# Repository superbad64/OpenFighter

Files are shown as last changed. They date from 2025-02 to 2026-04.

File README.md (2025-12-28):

  

# Open-source 3D printable fightstick cases for the crafty warrior

A gaggle of case builds intended to be mostly 3D printed.

## How's it works

Builds are assigned (very subjective) stats on a scale of 1 to 5 vaguely describing what my own experience was putting them together:  

- **Printability**: How easy they are to print. Most of the time PLA is assumed to be the material of choice. 5 means if your machine squirts plastic it should work; 1 means you pretty much need a perfectly tuned printer to do it. Anything below 1 means it has only ever worked on my personal printers during what can be generously called a freak accident.
- **Buildability**: How easy they are to actually put together. 5 should be roughly equal to your average LEGO Technic build; 1 means you need a PhD in rocket surgery.
- **Extra hardware**: How much non-printed hardware and tools is needed to build (generally proportional to the price). **This only concerns the case itself; electronics are not considered part of it** (except when noted). 5 means you only need heat-set inserts and corresponding screws at best; 1 means you need to source some stuff that may be harder than average to get. (Do note that usually acrylic is considered "to taste" and doesn't factor into this particular note)
- and finally, **Price**: Because of course this is a deciding factor for a lot of people. 5/5 means it's super cheap to make; 1/5 means I had to sell my house to make it.

## The gallery

Goblin: Flatbox-style build  
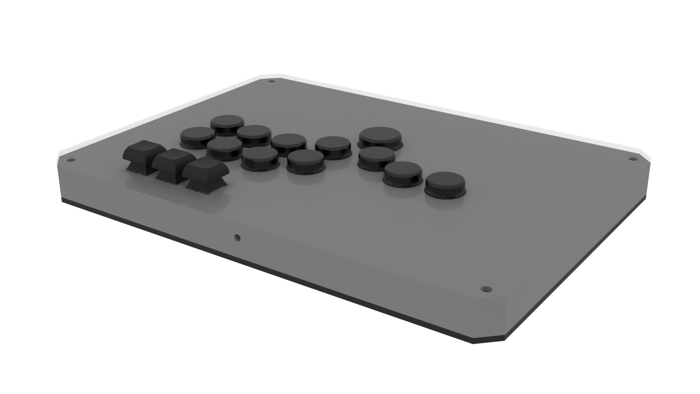
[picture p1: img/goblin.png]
Goblin


Ikari: Tented ergonomic build
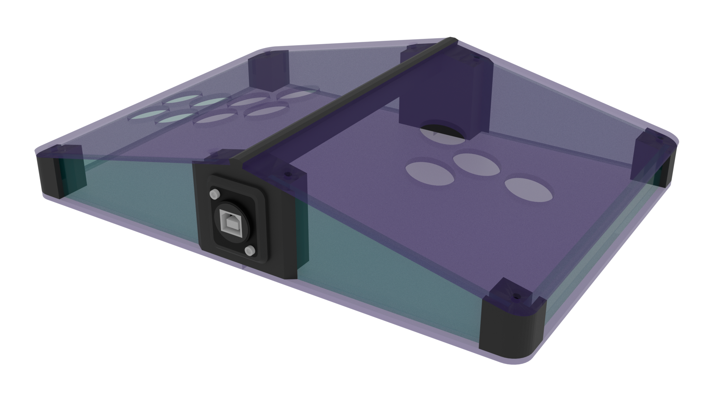
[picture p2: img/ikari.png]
Ikari


Ogre: American-style build
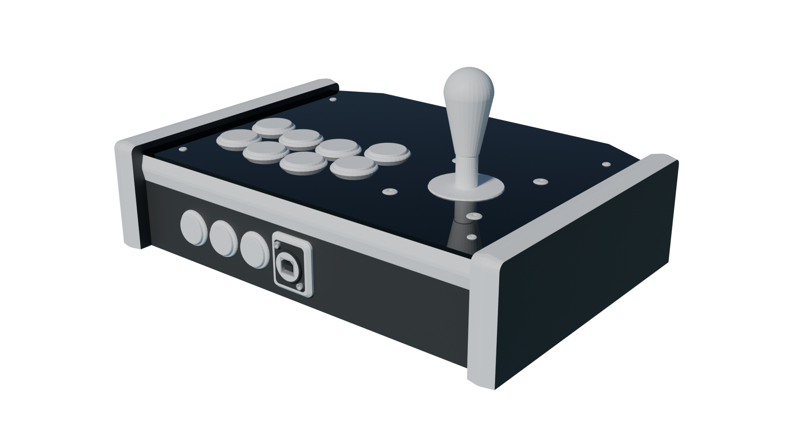
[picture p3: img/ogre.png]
Ogre


Ork: All-rounder compact build
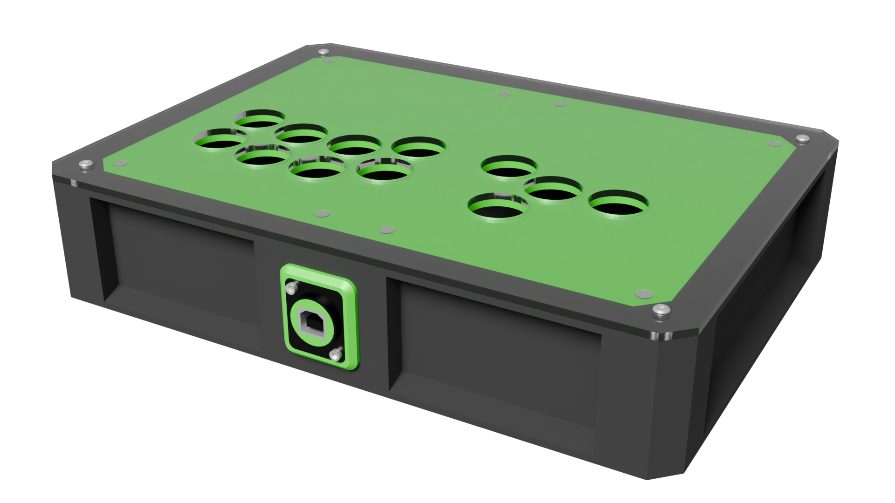
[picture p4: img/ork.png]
Ork


Unhinged: Clamshell design for easy access to the internals
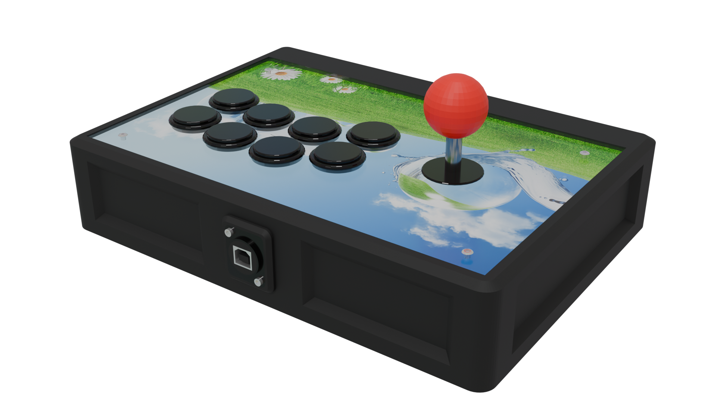
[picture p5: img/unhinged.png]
Unhinged


Wanderer: Cheap straightforward build
Wanderer

Tteokbokki Top Grade: Rough equivalent to "OC Do Not Steal"
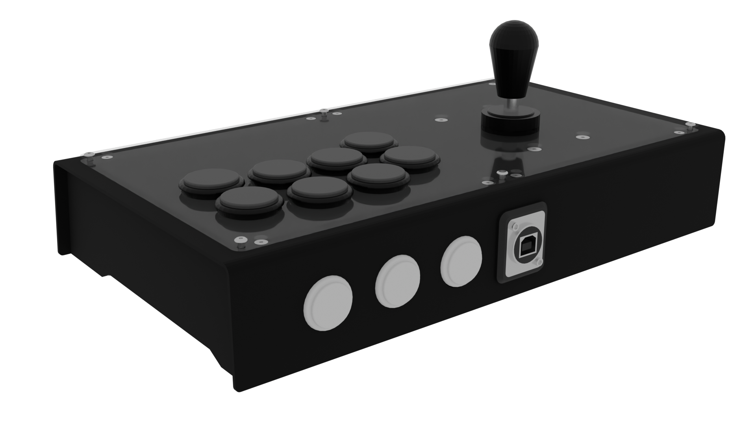
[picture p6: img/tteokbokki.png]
Tteokbokki


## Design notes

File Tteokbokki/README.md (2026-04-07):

# T.T.E.O.K.B.O.K.K.I. Top Grade Case
## Also known as "We have [REDACTED] at home"

Non-copyright-infringing case

---

A case that I swear no one has ever seen around. Comes with a magnetically attached bottom plate (if you want it to; otherwise it's M3 Screw Land).

## The Stats

**Printability**: 4/5; You do need a setup that is particularly good at bevels and supports; I use tree supports for the frame  
**Buildability**: 4/5; Large, roomy case with plenty of internal space  
**Extra hardware**: 3/5; Does need a fair amount of screws, and also magnets  
**Price**: 4/5; The hardware drives the BOM up a little on this one but nothing too cray cray  

## Some context and questions I've been asked about it

A few months ago I made the [Raijin](https://github.com/superbad64/OpenFighter/tree/main/Personal%20Builds/Raijin) out of a desire to have a full-collar Korean build. Due to the frankly ludicrous BOM on it, I decided to revisit it, and the end result happened to be this very build.

For printability's sake I made one with full sides, instead of the recessed ones pictured above. The files for it are also available in the STL folder.

Do keep in mind that this was *supposed* to be filled, sanded, primed, and then painted to hide the joint seams; therefore some of the conception really does not account for a default "extruded plastic" look. (It works though, but that's more a happy accident than anything else)

## Parts list

Must be exactly matched:

- M3S Ruthex heat-set inserts:
    - 6 for the acrylic
    - 8 for the top panels
    - 8 more if you're using the screw-on bottom
- 1x A3-sized 2 or 3mm thick sheet of material to drill or laser cut for the top panel (acrylic, wood, brass, dry ice, aerogel...)

Exact match not needed except for dimensions:

- DIN 7991/ISO 10642 M3x8 hex socket countersunk screws for the top panel halves
    - 8 for the top panel halves
    - 8 more if you want the screw-on bottom panel
- 6x ISO 7380 M3x8 hex socket button head screws for the acrylic
- 4x DIN 7991/ISO 10642 M4x16 hex socket countersunk screws to mount the lever (if you choose to have one of course)
    - In a pinch, M3x16 also works as long as you're using a washer
- 2x DIN 912/ISO 4672 M3x30 hex socket head cap screws for the Neutrik
- M3 nuts and washers (just grab a handful)
- 8 or 12x 15 by 3 millimeters disc-shaped magnets if you want the magnetic bottom (I find 8 to be largely enough but you do you)
- 4x 6x30mm dowel rods (you can just print them anyway, they're just cylinders)

Tools && auxiliaries:

- Soldering iron
- Multi-purpose pliers to tighten all those nuts
- Neoprene glue/contact cement
- (Optional but **vigorously** recommended) *Long* ratcheting clamps
- (Optional but recommended) Medium strength threadlocker, aka blue Loctite(tm)

## Build guide

Print both frame halves and carefully remove the supports. Insert the dowels in the guiding holes and join the halves together, using neoprene glue.

> [!IMPORTANT]
> While I'm unsure of the exact effects of neoprene glue fumes on the human body/nervous system, it seems like a good idea to avoid spreading said glue too close to the holes into which a heat-set insert is going to be added in a few moments.

If you have some, use the ratcheting clamps to make sure everything is super tight (you shouldn't *need* to but it can't hurt). Let the glue cure for a day.

Add the heat-set inserts to the holes on the top side. Screw in the top panels of your choice using the inner holes (relative to each panel); the outer holes are for the acrylic.

Use some more neoprene glue to attach half of the the magnets to the frame. Whilst being mindful of the polarity, attach the other half to the bottom panels.

Join the three bottom panel parts together using... you guessed it, neoprene glue. After curing, you can plastic weld the non-glued parts to further improve stability.

## TODO

- Art && cut files

## Acknowledgements

- [Buttercade](https://www.etsy.com/shop/BUTTERCADE) for the Surround and Support project
- [The GP2040-CE project](https://gp2040-ce.info) for the GP2040-CE firmware
- Sega for the Virtua Stick High Grade
- By proxy, Etokki for the Omni

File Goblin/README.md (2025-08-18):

# G.O.B.L.I.N.
## Flat case and a good weekend project

I was rendered in Cycles and took like an hour... but at least I'm not EEVEE

---

A Flatbox-style build in two flavors: WASD and Standard. Uses Cherry MX style switches, compatible with SiTong caps. Requires you to vaguely know how to operate both a 3D printer and a soldering iron.

The main difference with the OG Flatbox is that this is a bit chonkier, and uses regular keycaps for the options row.

## The Stats

**Printability**: 5/5 (very few supports, as long as you have a good bed level it should be a breeze)  
**Buildability**: 4/5 (you will need to have solid bases in soldering to get this done)  
**Extra hardware**: 4/5 (all of it can be easily bought online for cheap)  
**Price**: 5/5 (it's about the cheapest controller I can make)

## Materials needed

- 4x M4 x 20mm "Chicago bolts"
- 15x MX-style switches
- (Optional) 15x MX-style hotswap sockets (in case you want to change your switches further down the line)
- 12x round caps (see below)
- 3x square keyboard caps
- 4x 200 by 3mm metal rods (either brass or steel, to taste)
- A board capable of running GP2040-CE (I used a Waveshare RP2040-Zero)
- Wire (solid core && stranded)
- Wire strippers
- Soldering iron (preferably one with adjustable temperature)
- (Optional) Cuttable screw terminals, or Wago style terminals

## Printing

Print the chassis halves. Print the bottom pieces. Print the top pieces if that's what you want, or go get some acrylic laser cut.

I swear it's *that* straightforward.

## Building

Assemble the two top halves, using the rods for alignment and support. Put your outbound USB cable in the hole. Plastic weld or glue if you feel like it. Do the same for the bottom halves.

Insert all your switches in the square holes; they're friction fit. Save the caps for later.

Use the solid core wire to wrap hooks (or loops if you're really dextrous) around the pins of the switches. If you use hotswap sockets, you might need to strip some extra. Solder those hooks and go from pin to pin until you have grounded all your switches. (You don't need to ground them all on the same rail, it just helps if you have a limited number of ground pins)

At this point you have a couple of options, all valid:  
- Leave a length of solid core wire after you're done hooking everything up, connect it directly to a ground pin on whatever board you use
- Do the same but a shorter length, use a Wago or screw terminal, and continue your ground path to the board with a stranded core wire
- Directly wrap stranded core wire above/around the last ground pin in the chain and connect *that* to the board

Switch to stranded core from this point onwards.

Measure lengths of wire and strip one end (don't be afraid of overdrawing at the wire bank so to speak - it's best to measure twice and cut once than it is to try to splice bits of wire together afterwards). Solder that end into your board.Measure how long you need to go to a given switch pin, add a couple centimeters, strip the wire, and wrap it around the switch pin to solder it.

Now how you make the board communicate with the outside world (and hopefully with a host type device such as a PC or a game console) is up to you; there are a lot of boards and even more cables, panel mounted cables, breakout cables and so on, and I realistically can't cover every case.

I encourage you to closely inspect your wiring job at this point, and most importantly test it !

Once you're done, set the caps onto your switches. Support them from the back while doing so to avoid damaging your wires.

Place your art (optional) and the acrylic on your top panel. Add the Chicago screw barrels. Place the bottom plate and screw it in place.

Let the Ikea Effect wash over you for a couple minutes before hitting the lab.

## Button Caps

You pretty much have two ways of going about this:

- Obtain a set of SiTong 24mm caps; those are 20.6mm across and will fit perfectly (don't forget to get a 30mm one - which is actually 25mm across - for the Standard Leverless layout) , **OR**
- Print them yourself (PLA is not recommended although that depends on your particular brand; PETG is much better). [Rana-sylvatica's keycaps](https://github.com/rana-sylvatica/circle-keycaps/tree/main) are a good bet, but anything with a MX compatible stem that is less than 21mm across should be okay

## Acknowledgements

- [jfedor's Flatbox](https://github.com/jfedor2/flatbox) for being the OG inspiration
- [The GP2040-CE project](https://gp2040-ce.info) for being an awesome firmware and for their Discord server re-teaching me how to solder

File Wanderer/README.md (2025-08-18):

# W.A.N.D.E.R.E.R.
## Very simple build

Eye of newt and hair of Shelob, now everyone can see your bad wiring job

---

This case is intended for a (relatively) compact and simple build with all the features you'd normally expect in a modern fightstick, except art support.

## The Stats

**Printability**: 5/5 (nothing to talk about)  
**Buildability**: 5/5 (your little sister can probably do it)  
**Extra hardware**: 5/5 (nothing unusual either)
**Price**: 5/5 (as cheap as a full size case can get)

Really the only problem is that the case is a little plain looking. YMMV.

## Parts list

Must be exactly matched:

- 16x M3S Ruthex heat-set inserts
- 1x Neutrik NA-USB

Exact match not needed except for dimensions:

- 16x DIN 7991/ISO 10642 M3x8 hex socket countersunk screws
- 2x DIN 912/ISO 4672 M3x35 hex socket head cap screws for the Neutrik
- 2x DIN 934/ISO 4032 M3 hex nuts

It's Whatever (tm):

- 3mm thick material for the sides (acrylic, 3D printed plastic, wood, metal, cardboard, marble, dry ice...)

Tools && auxiliaries:

- Soldering iron
- (Optional but recommended) Medium strength threadlocker, aka blue Loctite(tm)

## Build guide

Print the two center joints (`centerfront` and `centerbottom`) upside down to minimize support usage.

Print the four corner posts (`post`) and add the magnets at the bottom, checking that they have the same polarity.

Print the bottom pieces, add the magnets while being careful that the polarity matches with those on the posts (in case this needs to be said outright, the posts should all attract the bottom plates).

At this point you have two (not mutually exclusive) choices:

### The Laser Way

Congratulations, you found a couple of nice sheets of 3mm thick material !  
Bring the laser cut files to your favorite shop and laser away. It's kind of that simple.

### The Printer Way

Actually it's mostly the same thing, except you just upload the STL files to your printer and wait the requisite amount of hours. (Specifically: one `left`, one `right`, and four `bridge` for the sides; and both halves of whichever top you pick)

### Moving on

Assemble the frame pieces together, without the corner posts. Slot in your top panels, and then screw the posts in. Optionally, weld the top panel halves together from the inside.

Add your electronics (I know, this is a vague step, but that's as general as I need it to be)

Screw in your bottom panel (you can also weld it from the inside).

Boom, fightstick !

## TODO:

- HitBox
- WASD

## Acknowledgements

- [Buttercade](https://www.etsy.com/shop/BUTTERCADE) for the Surround and Support project
- [Arcade Shock](https://arcadeshock.com/products/fs-traveler-acrylic-controller-case-choose-type) for the Traveler which largely inspired this project

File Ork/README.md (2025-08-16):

# O.R.K.
## Regular fightstick case

> [!NOTE]
> This case is currently being remade from scratch. Stay tuned !

Waaaaagh !

---

An all-around, semi-compact case that has the footprint of an A4 sheet. Supports art prints.

## The Stats

**Printability**: 5/5 (no gimmicks)  
**Buildability**: 4/5 (press-fit is a little hard but nothing insurmountable)  
**Extra hardware**: 5/5 (nothing outside of acrylic and heat set inserts)  
**Price**: 4.5/5 (it does need a lot of filament but nowhere near the Ogre, so it's still fairly cheap)

## Parts list

Must be exactly matched:

- 20x M3S Ruthex heat-set inserts:
    - 8 for the bottom panels
    - 8 for the top panels
    - 4 for the acrylic
- 1x A4-sized 3mm thick sheet of material to laser cut for the top panel (acrylic, wood, brass...)

Exact match not needed except for dimensions:

- 4x ISO 7380 M3x5 hex socket button head screws for the acrylic
- 24x DIN 7991/ISO 10642 M3x8 hex socket countersunk screws:
    - 8 for the bottom panel
    - 8 for the top panel
    - 4 for the acrylic
    - 4 to mount the lever (if applicable)
- 4x DIN 7991/ISO 10642 M4x10 hex socket countersunk screws to mount the lever
- 2x DIN 912/ISO 4672 M3x30 hex socket head cap screws for the Neutrik
- 4x M3 washer (also for the lever if there is one)
- 6x DIN 934/ISO 4032 M3 hex nuts

Tools && auxiliaries:

- Soldering iron
- (Optional but recommended) Neoprene glue/contact cement. CA glue should work too
- (Optional but recommended) Medium strength threadlocker, aka blue Loctite(tm)

## Build guide

Print four corner pieces, the left and right ones, front and back dividers, the four short sides, then the bottom file twice. Press fit all parts of the frame together (clamps might help). Add heat set inserts.

Pick a layout and print the top plates. Screw them to the frame. Get your art printed, your acrylic cut, and add them to the top. Secure with screws.

Time to build the electronics !

## TODO

- Sega 2P layout
- Better render
- All art & cut files

## Acknowledgements

- [Buttercade](https://www.etsy.com/shop/BUTTERCADE) for the Surround and Support project
- [Junk Food Arcades](https://junkfoodarcades.com) for the Snack Box v2, which genuinely coincidentally happen to share a lot of general shapes with this project)
- [The GP2040-CE project](https://gp2040-ce.info) for the GP2040-CE firmware

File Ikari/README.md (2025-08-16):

# I.K.A.R.I.
## Tented ergonomic build

> [!NOTE]
> This is a WIP ! It's not yet quite ready to be actually brought into the physical world.  
> *Hic sunt dracones.*

Fiendishly plotting

---

Sloped build to reduce wrist pain. Originally envisioned as a pure acrylic cut build, turns out it's also printable (who knew lmao). More info to come SOON(tm)

## The Stats

**Printability**: ?/5 (I haven't actually built one, but all the pieces are extremely simple geometry, so it should be a 5)  
**Buildability**: ?/5 (ditto)  
**Extra hardware**: Probably 1/5 if you run it in full laser cut acrylic as intended, and 5/5 if you print it (again, still haven't built one)  
**Price**: Probably -2/5 for the acrylic, and 5/5 for the printed one

## Parts list
TODO

## Build guide
Also TODO

## Acknowledgements

- [Buttercade](https://www.etsy.com/shop/BUTTERCADE) for the Surround and Support project
- [Arcade Shock](https://arcadeshock.com/products/fs-traveler-acrylic-controller-case-choose-type) for the Traveler which largely inspired this project

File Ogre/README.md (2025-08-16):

# O.G.R.E.
## American-style fightstick case

\<Kazoo rendition of The Star-Spangled Banner.mp3\>

---

## The Lore

This case is based on the venerable Multi Arcade System by the legendary Thao Nguyen (may he and his wife rest in peace). There are major differences though, which is why I call it an American-*style* case, rather than being a straight tribute.

The first and most obvious is the building material. Original MAS sticks were made of thick MDF, and while it's a nice building material, it also weighs a ton. I'm pretty confident that any printable plastic, even at 100% infill density, will result in a case that is *far* lighter than any MAS ever was. (*Note: I don't actually have a MAS so if you have one and can prove me wrong I'd actually genuinely appreciate it*)

To preserve at least the spirit if not the letter, laser cut files are provided for additional wooden accents to be glued onto the frame. MDF or plywood should work nicely as long as it's 3mm thick. Even acrylic if you're feeling adventurous and decide to slice the "wings" without top and bottom surfaces so as to partially see inside the stick. But should you want to, you could also just print them in a different color from the end of the frame !

The second major difference, also rather obvious, is that I elected to not slope the control panel inwards. To be honest I couldn't find data on what angle should be used, and since I am going to use that as a lap stick anyway, I decided to forgo this part entirely.

Third big difference: The button layout has been adapter to something more hand-friendly (namely Sega 2P) and uses 30mm holes instead of the 28mm ones made for Happ-style buttons (including IL versions).

And the last difference: the build is a lot smaller than an original MAS (again done to be able to use it on my lap). The original is 40.64 x 25.40 x 12.7 centimeters, and this one is 32.8 x 23.2 x 7.8 centimeters.

## The Stats

**Printability**: 3.5/5 (the external walls/"wings" really suck and take way too much time to print, and every grooved part needs support due to orientation)  
**Buildability**: 5/5 (super roomy case that is very easy to put together and build in)  
**Extra hardware**: 4/5 (technically you could print the dowels using a truncated cylinder, but the square neck bolts is where it loses a point for real)  
**Price**: 4/5 (eats about an entire roll of plastic to be willed into existence; not too bad but definitely the most expensive build I have on the roster)

## Parts list

Must be exactly matched:

- 28x 6x30 wood dowels
- 16x M3S Ruthex heat-set inserts (I haven't tested other ones, and I know *those* work)
- 1x Neutrik NA-USB
- 4x DIN 603/ISO 8678 M5x30 cup head square neck bolts (**THE SQUARE NECK IS IMPORTANT**)

Exact match not needed except for dimensions:

- 4x DIN 6923/ISO 4162 M5 hex nuts with flange (any M5 fastener will work but these are the ones I used)
- 4x ISO 7380 M3x8 hex socket button head screws
- 8x DIN 7991/ISO 10642 M3x6 hex socket countersunk screws
- 2x DIN 912/ISO 4672 M3x30 hex socket head cap screws
- 2x DIN 934/ISO 4032 M3 hex nuts

To taste:

- About a kilogram of filament (more if you wish to print accent pieces)
- Around 1m of T-molding, 19mm wide

Tools & auxiliaries:

- Soldering iron
- (Optional but recommended) A rubber mallet
- (Optional but recommended) Neoprene glue/contact cement. CA glue should work too
- (Entirely optional) Around 2 A4 sheets worth of 3mm thick material to laser cut
- (Entirely optional) One A3 size 3mm acrylic sheet for the top panel, also for laser cutting

## Build guide

> [!IMPORTANT]
> Currently the mounting points for the main board are misaligned.
> **I am aware of this.**
> If that is a problem for you, a temporary fix would be to use self-adhesive feet, but really you can pretty much leave the board hanging in there too. I will eventually fix this some day.

Start with the two main body halves and the support bracket, all located in the Common folder. Use five dowels (and glue if you have to) to join the halves. Add the heat-set inserts: 6 holes on the underside of the body, 2 in the support bracket, ~~4 holes on the right side to mount the board~~, and 4 holes on top to mount the acrylic.

Print both sides of the fender, and join them with one dowel. Add four more (and again, glue if you need to) then join it to the main body. This will also lock the main body permanently !

Add the T-molding to the main body. Use whatever you deem necessary to make it behave and slot in properly. Glue, clamps, heat gun -- anything is fair game.

Depending on whether you're going for accent panels or not, pick your wing model from the appropriate folder. The wings are symmetrical, so start with whichever side you find more convenient. Add dowels to the main body; if you're hammering them in, only hammer the 6 outer ones in since the 3 middle holes do not bottom out !

- If you're going for the layered approach: go for (glue) -> side with holes -> (glue) -> inner wing -> (more glue) -> outer wing -> t-molding
- If not, just slide it in and add your t-molding after

Screw in your top panel acrylic if you have one; add the square neck bolts to your top panel and secure them (if you already have the lever on hand, it's time to install it as well)

Add the Neutrik to the main body, then the support bracket

Print the bottom piece twice and screw it to the body.

## FAQs:

Q: Which levers are compatible with this ?  
A: This case is made for the Industrias Lorenzo Eurostick 2. For any other lever, you will need an adapter plate. I do not know *which* adapter plate though, sorry !

Q: Which buttons are compatible with this ?  
A: They should all be compatible. You might have trouble fitting Happ-style buttons without a shim (just a hollow barrel or ring, ID 28.1mm OD 29.9mm 3mm high if you wanna model one yourself)

Q: Can I print the parts that should be made of wood/acrylic ?  
A: Sure ! Contact cement works just as well to attach them.

Q: T-molding is a PITA ! Any suggestions to deal with it ?  
A: Frankly I used weak adhesive (read: regular school-grade glue) to make mine behave. If you have a heat gun that also works, just be careful to not melt the plastic !

## Acknowledgements

- The Nguyen family of course, for creating the MAS in the first place, and by proxy the very concept of fightsticks
- [Buttercade](https://www.etsy.com/shop/BUTTERCADE) for the Surround and Support project

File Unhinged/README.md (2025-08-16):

# The Unhinged
## Fabled clamshell design of legend

> [!NOTE]
> This build will probably be either deleted or remade from scratch to address some of the building issues.

Ironically, very much hinged

This compact build offers a clamshell design for easy access to the internals.

## The Stats

**Printability**: 5/5 (none of the pieces are hard to print, but...)  
**Buildability**: 2/5 (...there are lots of problems to actually put the lid together)
**Extra hardware**: 2/5 (the door ball catch is *really* specific)
**Price**: 3.5/5 (not too bad but the hinge hardware does affect the final BOM)

## Parts list

Must be exactly matched:

- At least 16x M3S Ruthex heat-set inserts (I haven't tested other ones, and I know *those* work):
    - 6 for the bottom panel
    - 2 for the door catch
    - 8 for the hinge bases
    - Add 4 more if you're using a lever
- 1x Neutrik NA-USB
- Door ball catch, 40mm long, with M4 holes 34mm apart (center to center)
- 1x A4 sized 3mm thick sheet of material to laser cut for the top panel (acrylic, wood, brass...)

Exact match not needed except for dimensions:

- 4x ISO 7380 M3x8 hex socket button head screws for the acrylic
- 6x DIN 7991/ISO 10642 M3x8 hex socket countersunk screws for the bottom panel
- 2x DIN 912/ISO 4672 M3x8 hex socket head cap screws for the door catch (the holes are M4 but the wider head works to hold it down fine)
- 6x DIN 912/ISO 4672 M3x25 hex socket head cap screws for the hinges (technically you need 4 M3x25 and 2 M3x10)
- 2x DIN 912/ISO 4672 M3x30 hex socket head cap screws for the Neutrik
- 12x DIN 934/ISO 4032 M3 hex nuts:
    - 4 for the top panel
    - 6 for the hinges
    - 2 for the Neutrik

Tools && auxiliaries:

- Soldering iron
- (Optional but recommended) Neoprene glue/contact cement. CA glue should work too
- (Optional but recommended) Medium strength threadlocker, aka blue Loctite(tm)

## Build guide

Print all parts of the frame (`left`, `right`, `centerfront` and `centerback` STLs), and 12 `dowel`. Join the parts together, using adhesive if you want to make sure the frame will not come apart under any circumstance. You can also weld the inner seams together. Add heat-set inserts to the 8 relevant holes (6 on the bottom, 2 on the center back joiner piece). Screw the door catch into the center back joiner piece.

Print the bottom panel pieces (`bottomleft` and `bottomright`) and screw them to the frame. Optionally weld them on the inside and/or apply adhesive to the lap joints.

Print the hinge pieces and assemble them: use an M3x25 screw and M3 nut to attach the base to the short arm, then a M3x10 to attach the short arm to the long arm. Bolt the hinge to the frame using M3x8 screws. Repeat for the other hinge.

Print the top panel pieces with the layout of your choice, and once again, optionally weld them on the inside. Attach the hinges to the top panel using M3x25 screws.

Next, print the `pin` file from the `Top` directory. This is the piece that will mate with the door catch, so I suggest printing it sideways, so the layer lines run perpendicular to the force vector applied when opening the case.

If you already have your laser cut acrylic (or wood or whatever else), mount it to the top panel.

Print the bezel pieces; use the aforeprinted pin piece and the laser cut plate as guides to glue them to the top panel.

## Acknowledgements

- [Buttercade](https://www.etsy.com/shop/BUTTERCADE) for the Surround and Support project

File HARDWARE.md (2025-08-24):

Here you will find a list of common hardware elements I use in almost all my builds and why.

---

## Screws

- **DIN 912/ISO 4672 Hex socket machine head screws**; Most of the time they're going to be M3x30 screws used for the Neutrik port (if there is one)  
- **DIN 7991/ISO 10642 Hex socket countersunk screws**; Usually M3x8, for things that need to be screwed down without any protrusion (mostly top and bottom panels)
- **ISO 7380 (no known DIN equivalent) Hex socket button head screws**; Also usually M3x8, I tend to use them for top panels/acrylic

If you're not a fan of hex screws, I found these Torx equivalents that are drop-in replacements (so long as you keep the same lengths)

- **DIN 912 TX/ISO 14579 Torx machine head screw**
- **DIN 7991 TX/ISO 14581 Torx countersunk screws**
- **ISO 7380-2 Torx button head screws**

## Mounting hardware

- **Ruthex M3S heat-set inserts**; You're probably familiar with those (and if you're not, you're going to be soon). Insert them into plastic using a soldering iron to get threads that are way better than modeled or tapped threads (into plastic anyway)
- **Steel or brass rods**; Butt-joining printed parts is a good step, but sometimes you need to take extra precautions to prevent the joined parts from bending. I usually stick to 200x3mm for practicality. I only tested those materials, I know RC enthuisiasts now deal with carbon fiber rods but I don't see the point for those builds.

## Aesthetic stuff

- **3mm thick acrylic sheets**; Well... If you don't know what this is I don't think I can help you. 3mm is a common size and helps with top panel stability. It doesn't actually *need* to be 3mm, it's just super convenient and easy to laser
- **Polymaker (Panchroma) Galaxy Black filament**; My go-to GOAT filament. Masks even super thicc layer lines (I usually print at .25mm). There are other brands and not just in PLA either (Prusa is known for their own Galaxy Black PLA blend, but they also have Galaxy Black PETG, and Polymaker does ASA too). I stick to PLA for the most part
- **Polymaker PolyTerra Charcoal Black PLA**; My other staple filament. Also really good at masking layer lines and giving the end product a more polished appearance. Like all matte PLA layer adhesion is a hair weaker than regular glossy PLA (not fully sure why), but since I usually print perpendicular to expected force vectors this is a non-issue

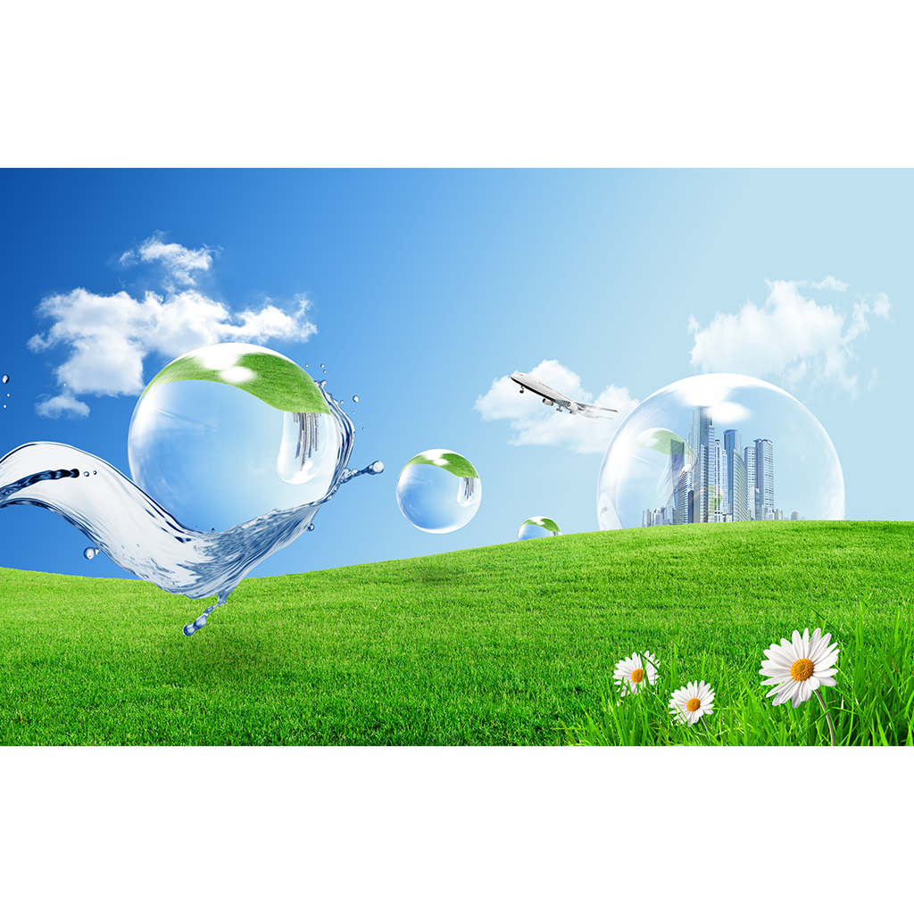
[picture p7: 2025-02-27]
Unhinged/artsample.png

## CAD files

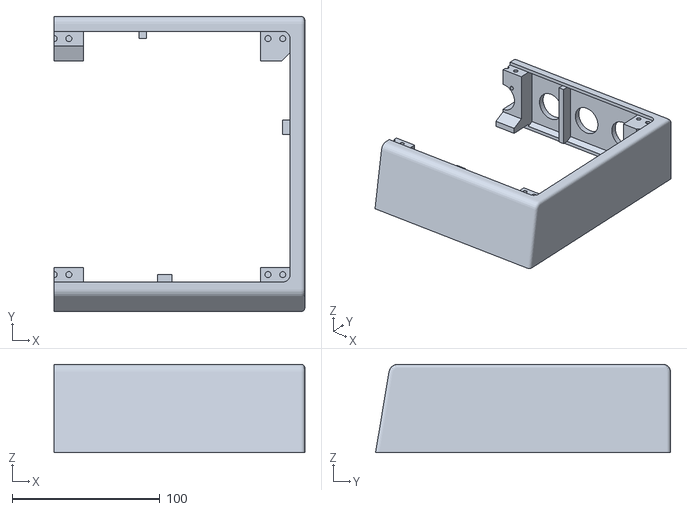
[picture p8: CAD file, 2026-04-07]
Tteokbokki/STL/Frame/Magnetic/Full sides/right_magnetic_full.stl
170.0 x 200.0 x 60.0

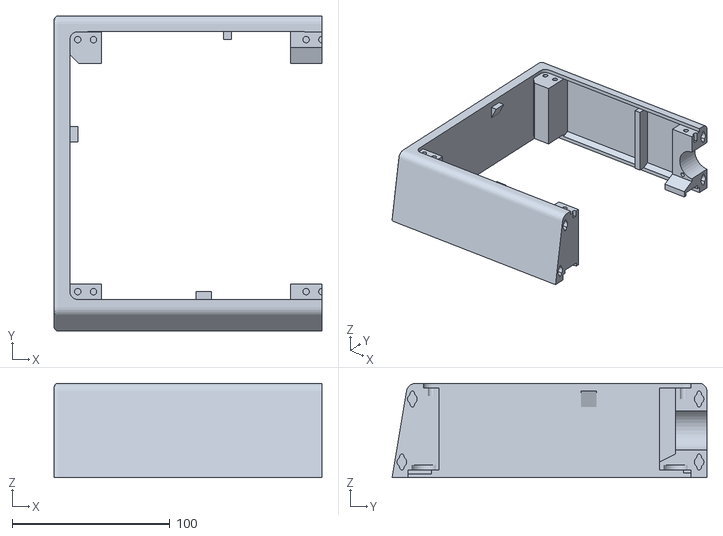
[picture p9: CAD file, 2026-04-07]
Tteokbokki/STL/Frame/Magnetic/Full sides/left_magnetic_full.stl
170.0 x 200.0 x 60.0

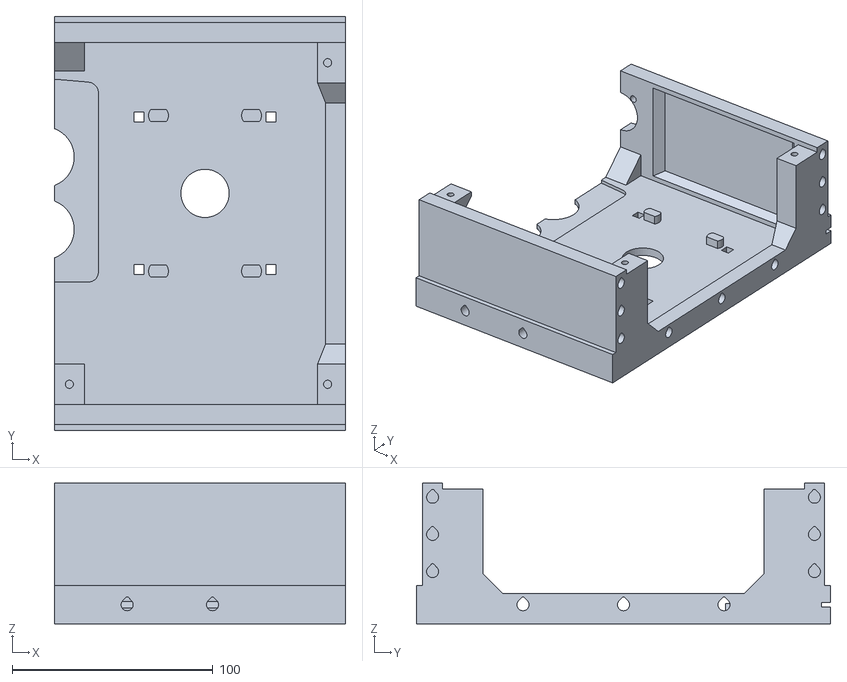
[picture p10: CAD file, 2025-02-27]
Ogre/Production Files/STL/Common/main body left.stl
145.0 x 206.0 x 70.0

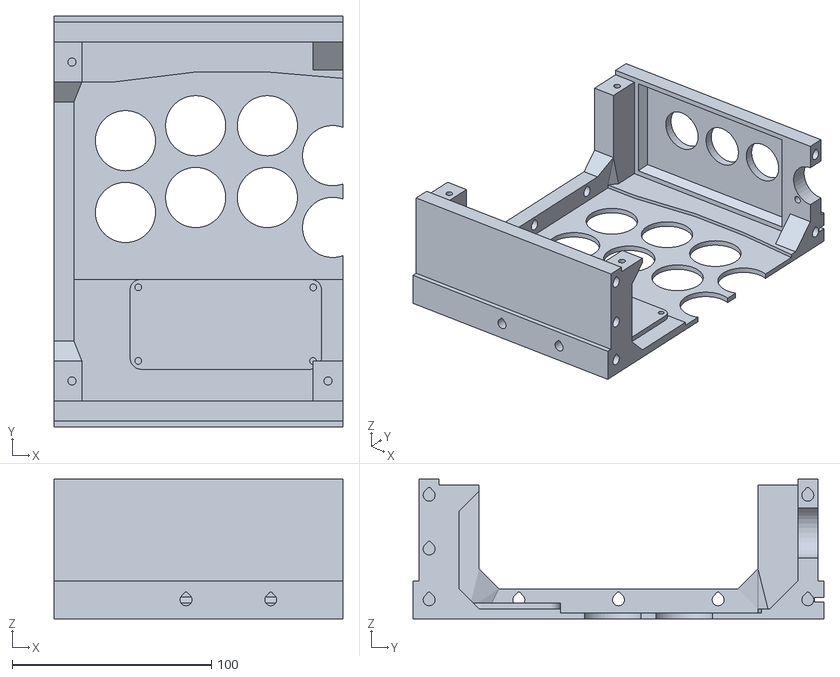
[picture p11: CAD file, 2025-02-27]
Ogre/Production Files/STL/Common/main body right.stl
145.0 x 206.0 x 70.0

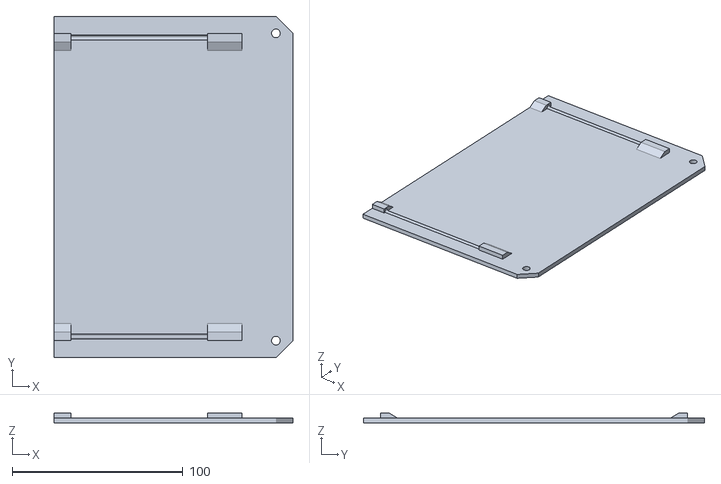
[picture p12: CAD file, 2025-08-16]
Goblin/Production Files/bottomright.stl
140.0 x 200.0 x 6.00

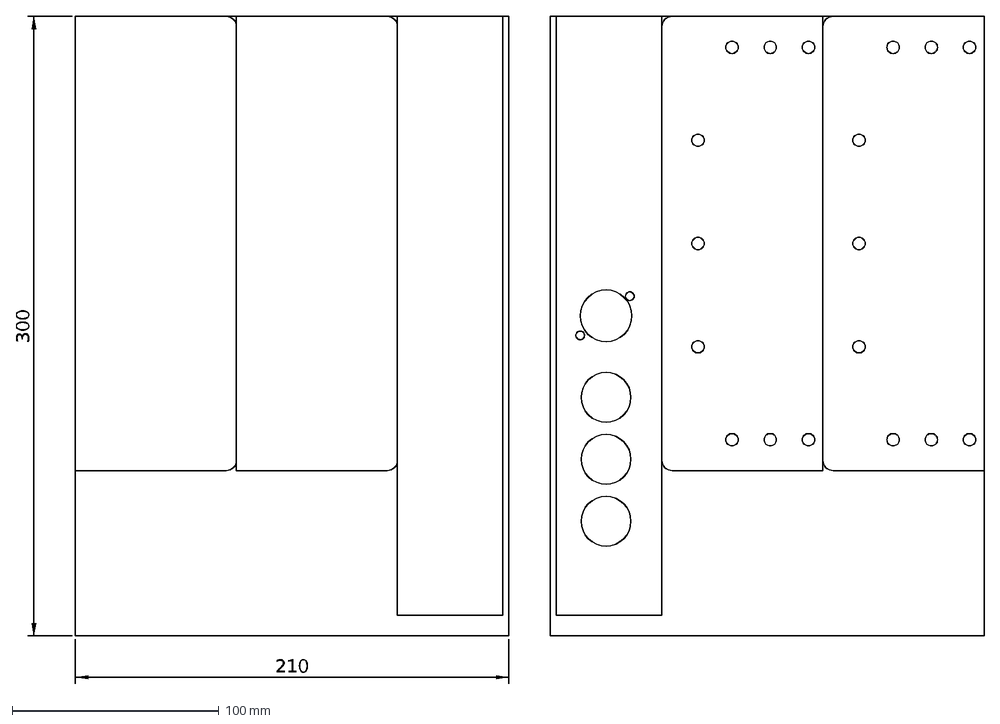
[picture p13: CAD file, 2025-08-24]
Ogre/Production Files/Laser Cut Templates/ogre all cuts.dxf
210
300

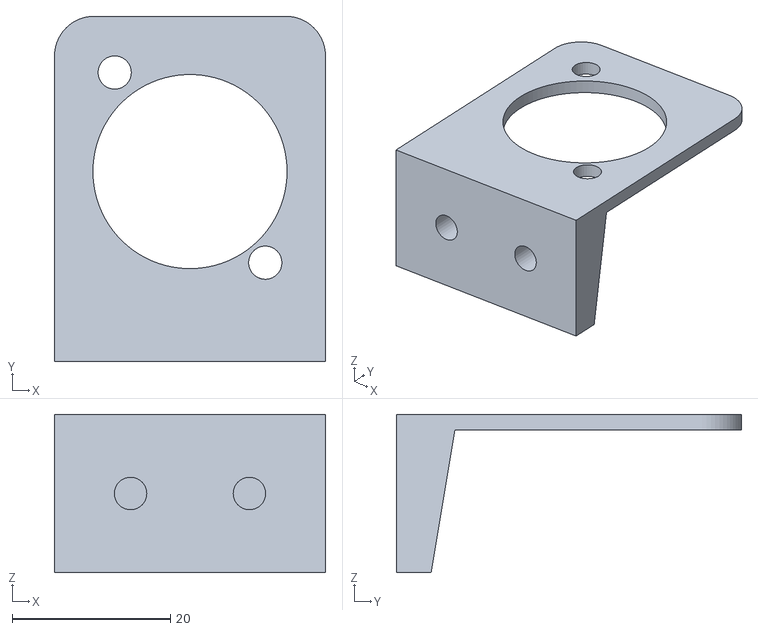
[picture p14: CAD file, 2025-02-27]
Ogre/Production Files/STL/Common/support bracket.stl
34.2 x 43.6 x 20.0

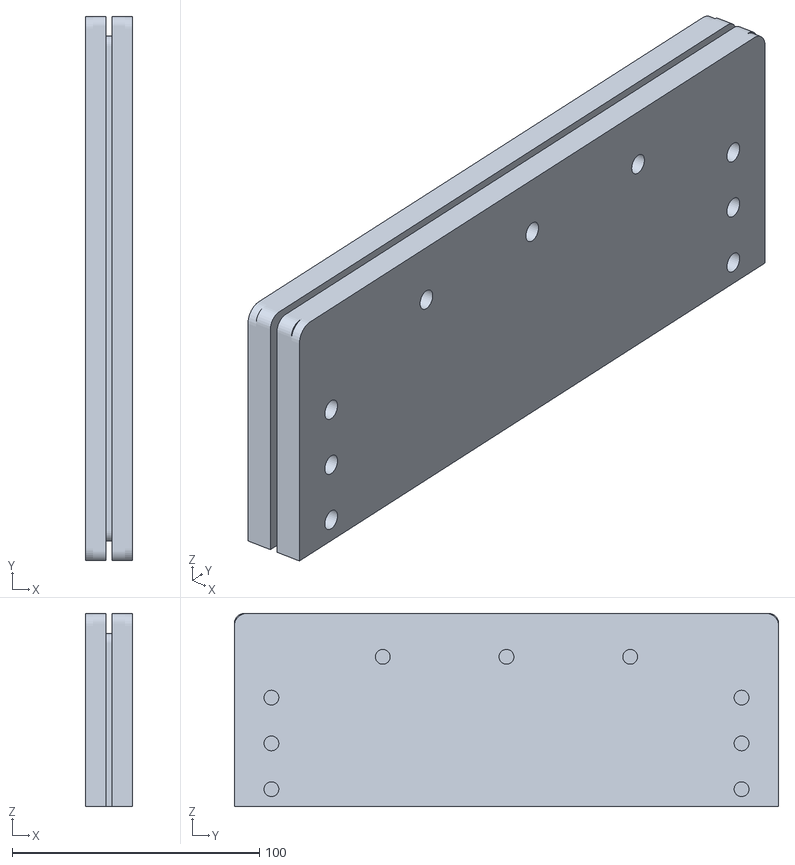
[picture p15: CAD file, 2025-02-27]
Ogre/Production Files/STL/No Wood/wing no wood panels.stl
19.0 x 220.0 x 78.0

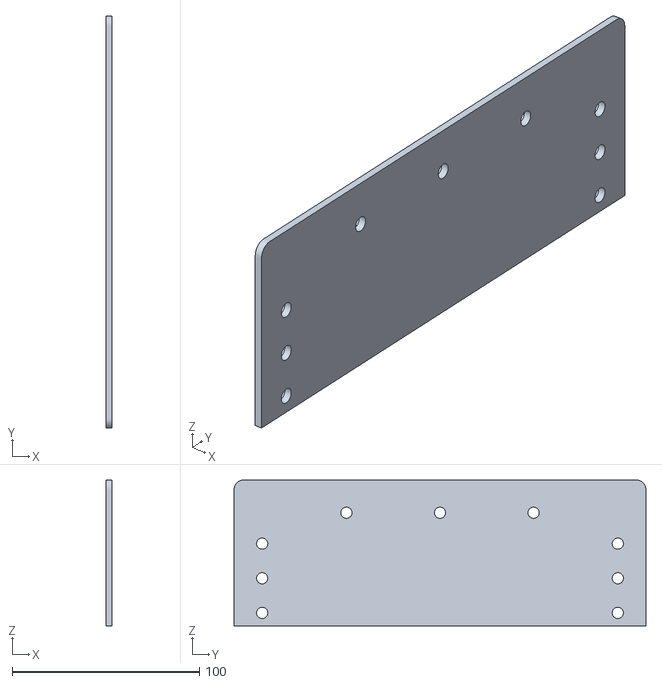
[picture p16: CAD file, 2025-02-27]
Ogre/Production Files/STL/Wood panels/wing dowel side.stl
3.00 x 220.0 x 78.0

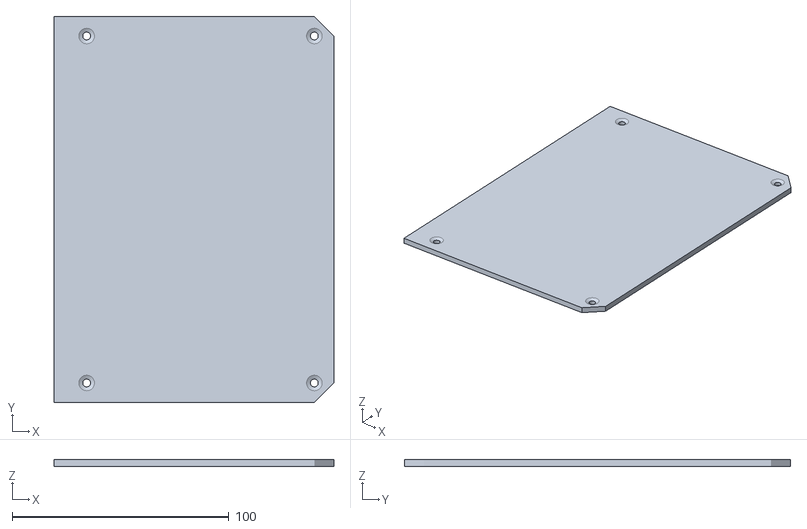
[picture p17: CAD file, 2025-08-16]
Ork/Production Files/bottom.stl
129.0 x 178.0 x 3.00

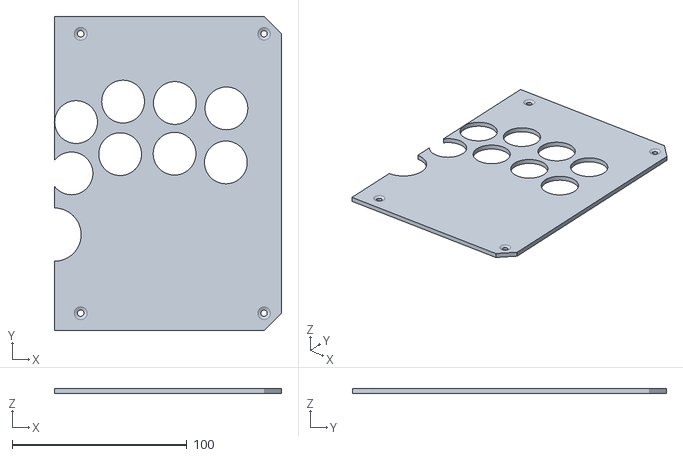
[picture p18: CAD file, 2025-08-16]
Ork/Production Files/Standard Leverless/standard_topright.stl
130.0 x 180.0 x 3.00

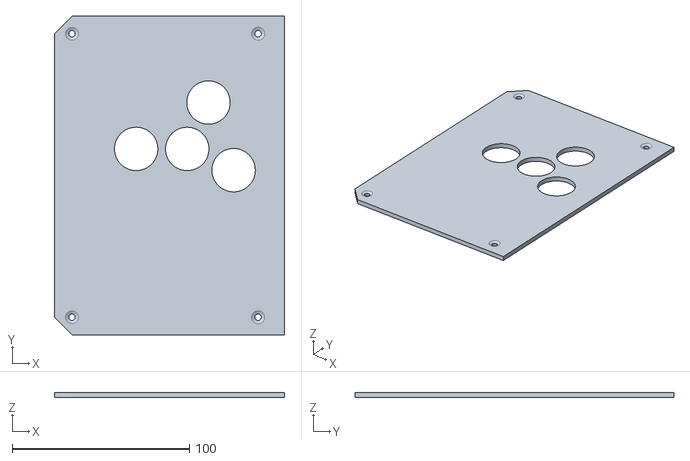
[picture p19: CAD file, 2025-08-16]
Ork/Production Files/WASD/wasd_topleft.stl
130.0 x 180.0 x 3.00

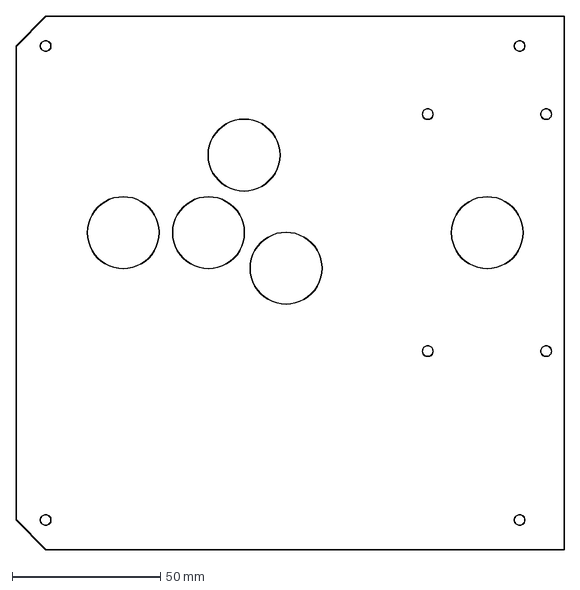
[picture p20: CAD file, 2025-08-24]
Personal Builds/Final Boss Neo/Laser Cuts/fbneo.topleft.dxf
185.0 x 180.0 mm

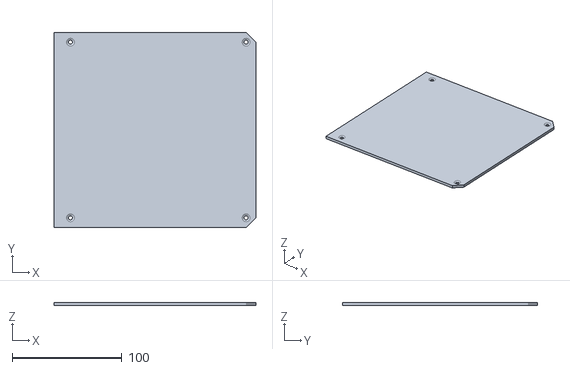
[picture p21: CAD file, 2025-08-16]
Personal Builds/Final Boss Neo/STL/bottom.stl
184.0 x 178.0 x 3.00

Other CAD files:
Personal Builds/Final Boss Neo/STL/Long sides/side_none.stl
Personal Builds/Final Boss Neo/STL/Surround Plates/surround_blank.stl
Personal Builds/Miniboss Neo/Cut files/miniboss_neo.dxf
Personal Builds/Raijin/Production Files/corner.stl
Goblin/Production Files/Standard Leverless/left.stl
Goblin/Production Files/Standard Leverless/right.stl
Goblin/Production Files/WASD/left.stl
Goblin/Production Files/WASD/right.stl
Goblin/Production Files/bottomleft.stl
Ikari/ikari.blend
Ogre/Production Files/Laser Cut Templates/#back.dxf
Ogre/Production Files/Laser Cut Templates/acrylic.dxf
Ogre/Production Files/Laser Cut Templates/back.dxf
Ogre/Production Files/Laser Cut Templates/cuts 1.dxf
Ogre/Production Files/Laser Cut Templates/cuts 2.dxf
Ogre/Production Files/Laser Cut Templates/front.dxf
Ogre/Production Files/Laser Cut Templates/wing external.dxf
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

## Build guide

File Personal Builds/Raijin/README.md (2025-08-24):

# R.A.I.J.I.N.
## ...A build. Most certainly.

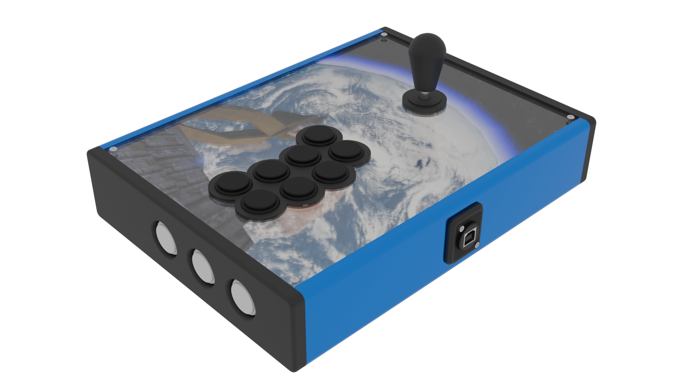
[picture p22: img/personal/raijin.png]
Thunder and lightning


---

A personal build because I *really* wanted to play with a full collar Korean lever again.

In other circumstances, I would call this a very simple, straightforward build. Because it's exactly that. Except...

## The stats

**Printability**: 5/5 (as straightforward as can be)  
**Buildability**: 5/5 (for my purpose anyway)  
**Extra hardware**: ...uhhhhhhhmmmmmm...  
**Price**: 4/5

## The elephant in the room

So if you've opened the STL files already, you might have noticed something that one would be inclined to describe as a pattern. If not, let me spoil you: This build requires **40** heat-set inserts and ~~just as many~~ even more screws somehow.

***FOURTY.***

Some people seem to not consider this a problem, and to be honest it *probably* isn't outside of my own head, but I personally find this number to be rather excessive - even if it does work, mind you ! You tell me if I'm overthinking this.

If you are too young to know what that art is, it's a legendary map from an equally legendary game that now allows you to play Fortnite.

## Parts list (buckle up)

No shortcuts this time: match these or go home !

- **40x** Ruthex M3S heat set inserts
- And 40x screws as follows:
    - 4x ISO 7380 M3x8 hex socket button head screws for the acrylic (can be substituted by machine head screws if you don't want to buy a bag of those to use only four)
    - 12x DIN 7991/ISO 10642 M3x8 hex socket countersunk screws for the top and bottom panels
    - 24x DIN 912/ISO 4672 M3x10 machine head screws for the frame
- And some more that don't have an inset counterpart:
    - 4x DIN 7991/ISO 10642 M3x16 hex socket countersunk screws with washers and matching nuts to mount the lever (or the same length in M4 with matching nuts if you don't want to use washers; you'll need to widen the hole manually though as it's M3)
    - 2x DIN 912/ISO 4672 M3x30 machine head screws with matching nuts for the Neutrik
- 1x 29 by 21 centimeters 3mm thick acrylic sheet

Tools and auxiliaries:

- Soldering iron (highly recommended if you intend for this build to go anywhere)
- Stiff drink
- Energy drink
- Stiff energy drink
- Size 2 and 3 hex wrenches or ball drivers depending on your personal preference

## Printing

Four corners, four brackets, four panel supports, two bottoms, one of each top half, left, right, and each cardinal direction (they correspond to the long sides but they're slotted to improve fitting)

## Building

Heat up your soldering iron. Crack your knuckles. Put on some lo-fi. We're here for a little while.

Place the heat-set inserts in all the relevant holes. I suggest doing this in one pass so that a) We're done with it, and b) The first inserts have the time to cool off and set-in by the time you finish.

Screw the long sides' halves together using the four brackets. Start adding the corner pieces using the machine head screws.

Screw in the short sides. Add the panel supports to them while you're at it (depending on how your printer's tolerances are tuned in, use either a rubber mallet, glue, or clamps to get this done)

Populate the top panels && acrylic and screw them in.

At this point we're entering the electronics zone, so this is where this guide stops !

## Post-mortem

I joke a lot in this README file but I don't actually think this is a bad build at all. In fact this might be one of my best IMO. I'm just very conflicted about the sheer number of screws required and whether or not it's "worth it" to someone who don't already have a ton of those laying around.

My version is actually a bit earlier than the one I published, and lacks the panel supports as well as the orientation markings. Seeing how that could rapidly get confusing I added those via ~~butchering the model~~ boolean modifiers.

Should you attempt to replicate my build, I do hope you like it, despite the gratuitous amount of screws !

## Acknowledgements

For once this build is entirely my fault from start to finish, so I guess shoutouts to SimpleFlips

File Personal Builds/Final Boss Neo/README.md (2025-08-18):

# Final Boss NEO
## Everything and the kitchen sink

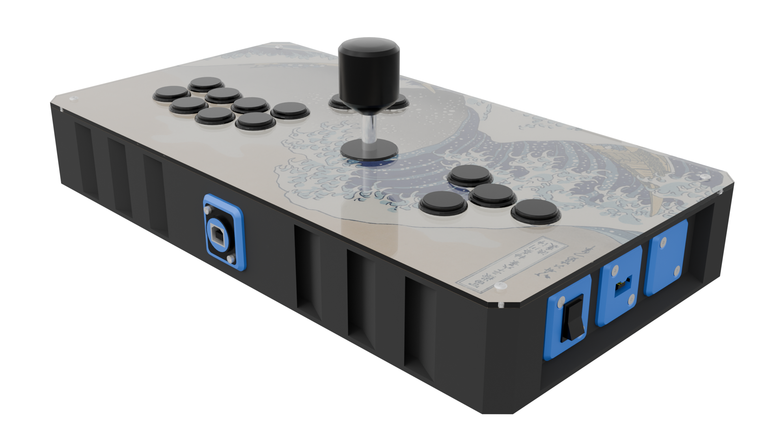
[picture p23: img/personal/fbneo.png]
Fighting the Final Boss


---

This is a wider (but not larger) variant of the Ork, in order to allow for a "Mixstick"-type layout. Since someone once asked what kind of directional input I preferred, and I decided to answer "Yes", this also includes a Nunchuk port. Because at this point why not.

The lever is detachable (Phreakmods Link) and therefore does not interfere with the WASD cluster. Also I picked this particular, non-standard order (most hitsticks/mixsticks go lever - movement buttons - action buttons) for two reasons: the first being to more closely mimic my typing position as I'm mainly a leverless player these days. The second is that, simply put, putting too much space between the lever and action buttons tends to introduce discomfort and misinputs alike while using the lever.

This decision, however, came to bite me in the rear during the build. More info below.

The lever and WASD clusters aren't active at the same time in order to comply with an EVO rule that I can no longer find. The grounds of both are wired to a 3 pole single throw switch acting as a selector out of an abundance of caution - sure, a 3 pole double throw switch would have worked much the same, and allowed me to enable both input sources at the same time, but just to mitigate the risk of making a tournament organizer mad on the day of, I elected to go for mutual exclusion instead.

The Nunchuk has been configured to be purely analog, which therefore *should not* break the rule on redundant inputs (this is the same rule that makes the Cross|Up tournament legal if you're wondering)

## The Stats

**Printability**: 5/5 (no tricky pieces at all)  
**Buildability**: 4/5 if you heed my warning and use a Sanwa JLX; 2/5 otherwise (and as someone who doesn't particularly like the JLX, this hurts to say)  
**Extra hardware**: 4/5 (the Nunchuk breakout might be the hardest part to get, which is really saying something)  
**Price**: 4/5 (for what it is, it's not bad)

## Parts list

Must be exactly matched:

- 20x M3S Ruthex heat-set inserts:
    - 8 for the bottom panels
    - 8 for the top panels
    - 4 for the acrylic
- 1x A4-sized 3mm thick sheet of material to laser cut for the top panel (acrylic, wood, brass...)

Exact match not needed except for dimensions:

- 4x ISO 7380 M3x5 hex socket button head screws for the acrylic
- 24x DIN 7991/ISO 10642 M3x8 hex socket countersunk screws:
    - 8 for the bottom panel
    - 8 for the top panel
    - 4 for the acrylic
    - 4 to mount the lever
- 4x DIN 7991/ISO 10642 M4x10 hex socket countersunk screws to mount the lever
- 2x DIN 912/ISO 4672 M3x30 hex socket head cap screws for the Neutrik
- 4x M3 washer
- 6x DIN 934/ISO 4032 M3 hex nuts

Tools && auxiliaries:

- Soldering iron
- (Optional but recommended) Neoprene glue/contact cement. CA glue should work too
- (Optional but recommended) Medium strength threadlocker, aka blue Loctite(tm)

If you wanna replicate my exact build:

- Angled USB-A to C cable (as low profile as possible on the A end)
- Seimitsu LS-32 (**SEE BELOW** - I heavily recommend not using this lever and using a Sanwa JLX instead)
- Phreakmods Link for the lever you use
- 17x Seimitsu PS-14-DN arcade pushbuttons
- 1x 3 pole single (or double if you're not paranoid about tournament rulesets) throw rocker switch
- 12x DIN 7991/ISO 10642 M3 hex socket countersunk screws for the accent plates:
    - 2x 35mm for the Nunchuk one
    - 4x 15mm for the rocker switch and the blank
    - 6x 5mm for the button plates
- 12x DIN 934/ISO 4032 M3 hex nuts
- 1x any board that runs GP2040-CE (I use the Advanced Breakout Board produced by Smallcab)
- 1x Brook wire harness (if applicable to the above)
- 1x Adafruit Nunchuk breakout
- Extra wire (a lot, preferably stranded)
- Crimping tool & 2.8mm spade connectors (just buy like a pack of a hundred, it's always useful)

## Build guide

Print 4x corner pieces, long sides of your choice (my builds use 2 vented sides for the front and 2 blank sides for the rear), both short sides, top and bottom panels. Add the heat set inserts into the frame then join the frame pieces. Screw down the top panels.

> [!WARNING]
>
> So this is where I need to talk about the lever. Since all I had on hand was a Seimitsu LS-32 and I was *really* not feeling up to spending an extra 70€ on purchasing both a JLX and a Phreakmods Link, I figured I should roll with that.  
>
> Turns out the LS-32 is kind of a big boy and it gets in the way of whatever plugs into the Neutrik, on the inner side. Thankfully, I had a left angled USB-A to C cable (right-angled would work just as well) that barely clears the LS-32's body and allows me to mount everything properly. If you're using a JLX, you'll probably be fine. If you're using basically any Korean lever, good luck.

Screw the Neutrik connector in the front, plug in the cable, then mount the lever to see if the clearance is good.

Mount everything that goes on a Neutrik style plate to the case. For the buttons, the screws are purely decorative and they're secured to the case through their own nuts.

Disconnect the ground of the joystick harness, crimp a spade connector on its end, then connect it to the rocker switch.

Wire everything else. Remember to use a separate ground chain for the WASD cluster and for the rest of the buttons, as we'll need to feed that to the rocker switch.

Crimp another wire that you'll connect to the common terminal of the rocker (usually the middle one, but check your datasheet nonetheless) and ground that to the main board. Wiring the rest of the stick should be pretty standard fare - in case you wish to ask, you can use the harness for the lever and connect the WASD buttons through the screw terminals, or the other way around, it doesn't really matter.

For the Nunchuk breakout, print an extra plate to use as a brace. Slide the adapter into the groove, then screw the holder plate and the brace plate on (the first one prevents the board from moving vertically, the second horizontally)

Wiring the Nunchuk breakout is kind of "to taste" and depending on what pins you have available. Check the GP2040-CE docs to know which i2c pairs you can use. Get 5v and ground from the screw terminals. If you can crimp a JST-PH connector you can also use the Expansion header normally used for the OLED display.

## Acknowledgements

- [Buttercade](https://www.etsy.com/shop/BUTTERCADE) for the Surround and Support project
- [Junk Food Arcades](https://junkfoodarcades.com) for the Snack Box v2, which genuinely coincidentally happen to share a lot of general shapes with this project)
- [The GP2040-CE project](https://gp2040-ce.info) for the GP2040-CE firmware and its Nunchuk add-on

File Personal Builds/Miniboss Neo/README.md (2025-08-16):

# Miniboss NEO

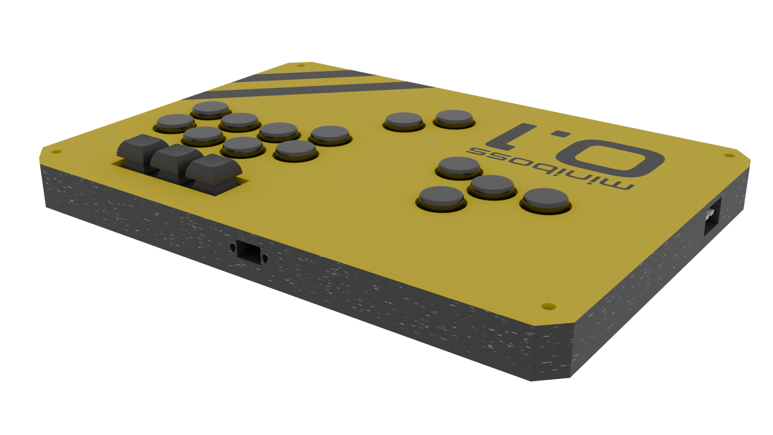
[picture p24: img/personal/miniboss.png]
I don't actually have a joke about minibosses


---

A variation on the Goblin build, adding two extra thumb buttons to a WASD layout alongside a Nunchuk port.

Originally I wanted it to have a standard acrylic plate && art (a 4K render of CTF-Face if you want to know), but at the time I completed this build, both my local printer and fablab were on vacation. Cue improvisation sequence.

## The Stats

**Printability**: 5/5 (very few supports, as long as you have a good bed level it should be a breeze)  
**Buildability**: 4/5 (it's basically identical to the Goblin, with four extra wires to deal with)  
**Extra hardware**: 4/5 (all of it can be easily bought online)  
**Price**: 4/5 (it's the Goblin with like five Euros more because of the Nunchuk breakout)

## Materials needed

- 6x M4 x 25mm "Chicago bolts"
- 17x MX-style switches
- (Optional) 23x MX-style hotswap sockets (way easier to solder to than bare pins)
- 14x round caps (see below)
- 3x square keyboard caps
- 4x 200 by 3mm metal rods (either brass or steel to taste)
- (Technically optional) 1x Adafruit Nunchuk breakout

## Printing

Print the chassis halves. Print the bottom pieces. Print the top pieces if that's what you want, or go get some acrylic laser cut.

I swear it's *that* straightforward.

## Building

Assemble the two top halves, using the rods for alignment and support. Plastic weld or glue if you feel like it. Do the same for the bottom halves.

Insert all your switches in the square holes; they're friction fit. Save the caps for later.

Use the solid core wire to wrap hooks (or loops if you're really dextrous) around the pins of the switches. If you use hotswap sockets, you might need to strip some extra. Solder those hooks and go from pin to pin until you have grounded all your switches. (You don't need to ground them all on the same rail, it just helps if you have a limited number of ground pins)

At this point you have a couple of options, all valid:  
- Leave a length of solid core wire after you're done hooking everything up, connect it directly to a ground pin on whatever board you use
- Do the same but a shorter length, use a Wago or screw terminal, and continue your ground path to the board with a stranded core wire
- Directly wrap stranded core wire above/around the last ground pin in the chain and connect *that* to the board

Switch to stranded core from this point onwards.

Measure lengths of wire and strip one end (don't be afraid of overdrawing at the wire bank so to speak - it's best to measure twice and cut once than it is to try to splice bits of wire together afterwards). Solder that end into your board.Measure how long you need to go to a given switch pin, add a couple centimeters, strip the wire, and wrap it around the switch pin to solder it.

Now how you make the board communicate with the outside world (and hopefully with a host type device such as a PC or a game console) is up to you; there are a lot of boards and even more cables, panel mounted cables, breakout cables and so on, and I realistically can't cover every case.

I encourage you to closely inspect your wiring job at this point, and most importantly test it !

Once you're done, set the caps onto your switches. Support them from the back while doing so to avoid damaging your wires.

Bask in the Ikea Effect before realizing you forgot to wire the Nunchuk breakout. For that matter, you haven't even printed its holding bracket. At this point I don't think I need to tell you how to proceed, do I ?

## Caps

You pretty much have two ways of going about this:

- Obtain a set of 14 SiTong 24mm caps; those are 20.6mm across and will fit perfectly, **OR**
- Print them yourself (PLA is not recommended although that depends on your particular brand; PETG is much better). [Rana-sylvatica's keycaps](https://github.com/rana-sylvatica/circle-keycaps/tree/main) are a good bet, but anything with a MX compatible stem that is less than 21mm across should be okay

## Acknowledgements

- [jfedor's Flatbox](https://github.com/jfedor2/flatbox) for being the OG inspiration
- [The GP2040-CE project](https://gp2040-ce.info) for being an awesome firmware and for their Discord server re-teaching me how to solder

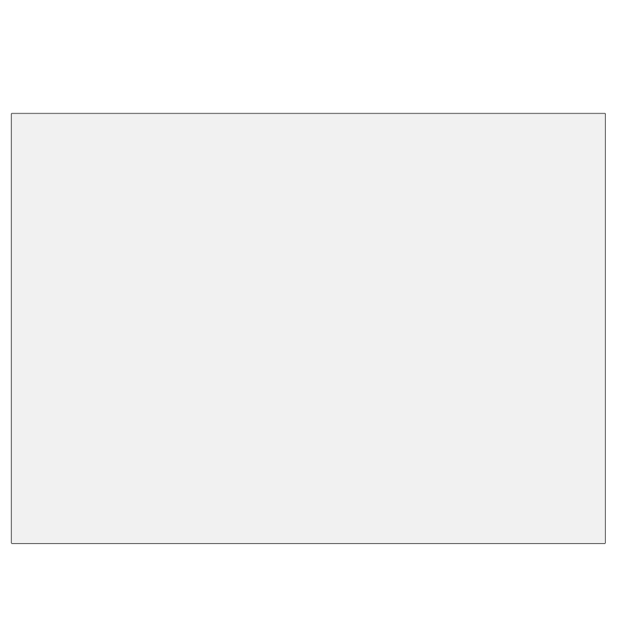
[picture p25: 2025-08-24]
Personal Builds/Raijin/uv.png

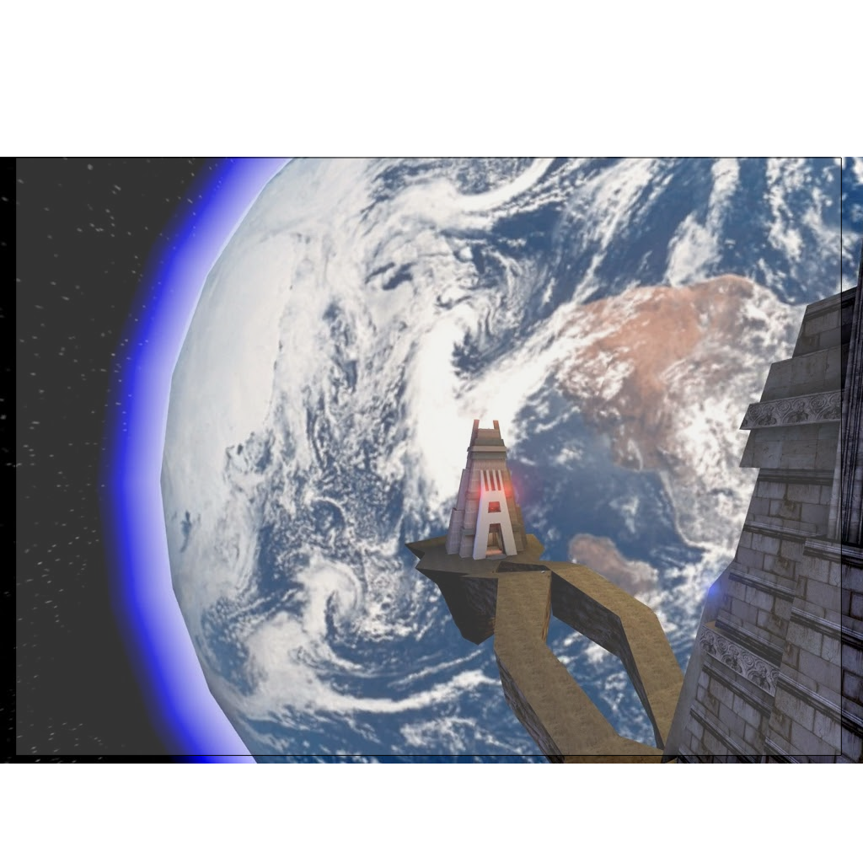
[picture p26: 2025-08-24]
Personal Builds/Raijin/art.png

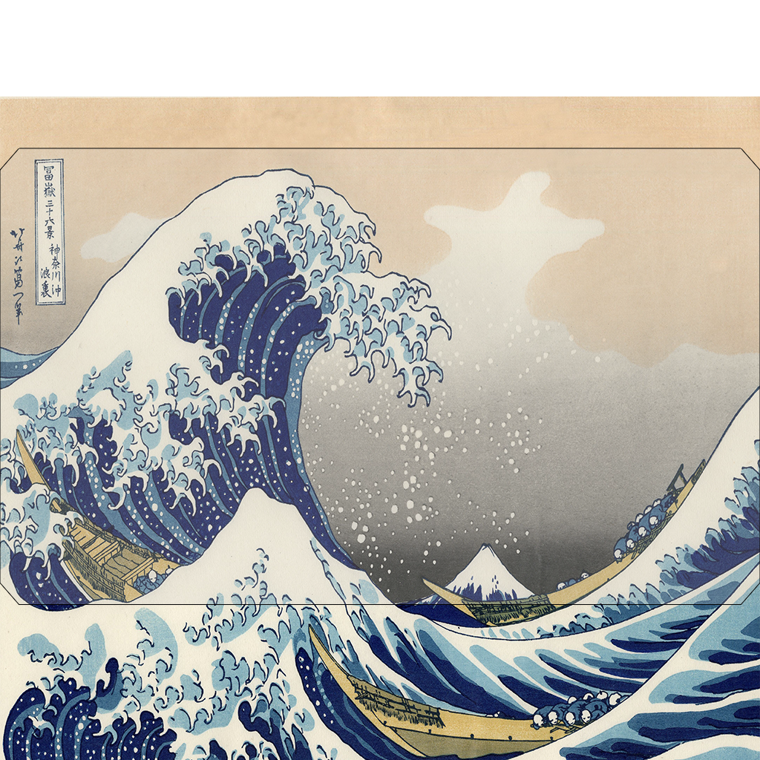
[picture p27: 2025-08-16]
Personal Builds/Final Boss Neo/fbneo_art.png

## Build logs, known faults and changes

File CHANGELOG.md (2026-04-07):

07042026:
Whew. Been a while huh ?
- Tteokbokki:
    - Redid the entire model to fix panel stability issues

24082025:
- New personal build: Raijin
- Wanderer:
    - Removed STL files pertaining to a magnetic bottom that never worked
- Added a general hardware guide

18082025:
- Goblin:
    - New version

16082025:
- Added a Personal Builds section with my own variants, Miniboss NEO and Final Boss NEO
- General:
    - Added judgemental metrics to let the users know how I evaluate a given build
- Goblin:
    - Put temporary in WIP status as I am redesigning the case from scratch
- Ork:
    - Redone from scratch for increased printability

12052025:
- Ikari
    - Added
- Wanderer:
    - Added "Next" variant

14032025:
- Wanderer:
    - Properly named bottom panel objects (whoops)
    - Added centering slots in bottom panels
    - Changed post magnet size from 3x3 to 4x5 so as to use the same model whether one wants magnets or heat-set inserts
    - Changed plate magnet size from 3x3 to 4x3 to match the above's diameter
    - Added WASD and HitBox layouts
    - Added mounting holes for mainboards

07032025:
- Added the Wanderer: a riff on Arcade Shock's Traveler, designed to be a simple, no-frills, easy to build experience

28022025:
- Moved to a new repo/account
- Dropped the Chimera entirely
- Ork:
    - Reworked the project from the ground up due to loss of files
- New case: Ogre (American style build)
- New case: Unhinged (clamshell style build)

10112024:
- Gnome/Goblin: (actual changes dated from November 7th; forgot to update this file)
	- Merged the projects (under the Goblin name) as the distinction is pretty much unneeded in the end
	- Reworked the entire case to use Cherry MX style switches && heat-set inserts
- Ork:
	- Changed all body holes to use heat-set inserts instead of captive nuts (This change has the goal of removing the need for me to be near the printer so I can print while at work)
- README.md:
	- Updated hardware list for heat-set insert usage

04082024:
- Gnome:
	- Reworked almost the entire top layer geometry
	- Added 2 extra millimeters to the body to better align with the button caps
	- Swapped the board to the next generation (prototype)
	- Added Choc stand-ins and their caps
- Chimera:
	- Changed color to blue to match the filament I'm gonna use (purely aesthetic)
	- WASD plate has been made thicker again

23072024:
- General:
	- Widened holes on Ork and Chimera to accomodate Crown buttons
	- Published STL files
- Chimera:
	- S2P top right panel now has grooves for snap-in buttons
	- Front right only takes two option buttons instead of three to alleviate routing issues

13072024:
- General:
	- Redid the models for the Eurostick and JLF(/JLX/archetypal Japanese lever of the week)
	- Redid the renders for the Ork and Chimera
- Ork:
	- Now has a completely separate 220x220mm Blender file

03072024:
- General:
	- Added an "Acknowledgement" section to the README to give proper recognition to whomever I got inspiration from
- Chimera:
	- Body magnets are now double-stacked to improve adhesion
	- Plate magnets are now exposed (but since the body magnets aren't there is no actual magnet-on-magnet contact,, preventing damage)
	- WASD plate has been reworked to print slightly faster and use slightly less filament

19062024:
- General:
	- Redid all the visuals
- Gnome and Goblin:
	- Adjusted overall thickness to 21mm to allow the buttons to sink in fully into the panel, accounting for cap printing tolerances
- Chimera:
	- Fixed missing geometry on top plates
	- Added a plate for an American lever
	- Made a recess in the bottom left plate just to make sure there won't ever be any clearance issues with any lever
- Or[c|k]:
	- Renamed to Ork for no reason in particular

11062024:
- Started work on the Chimaera

09062024:
- Retired Dwarf as a mini case
- Reworked Orc from the ground up to be a midsize unibody

21032024:
- General:
	- Cleaned up Gnome and Goblin directories
	- Reworked manuals to be a little more exhaustive
	- Added refs to the OneBoard repo since it exists now
- Gnome:
	- Added a version of the body for captive M3 nuts
- Goblin:
	- Added divots on the bottom plate to allow space for non-flush screws

03032024:
- Changes to Gnome:
	- Now separate from the Goblin
	- Basically remade the entire model

02032024:
- Gnome has been merged into Goblin as its v4
	- Gnome will become something else in the near future
- Changes to Goblin:
	- Quite a lot of PCB modifications, body piece has been redesigned entirely
	- PCB files have been added
	- Pics of alternate layouts have been added

270224:
- Created CHANGELOG.md
- Created the G.N.O.M.E., a smaller, one-piece Goblin (might merge with Goblin in the long run)

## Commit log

2025-02-27 Hard reset
    [Body Back Joiner.stl, Body Front Joiner.stl, Body Left.stl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]
2025-02-28 Cleanup && added missing STL files
    [left.stl, right.stl]
2025-03-07 Added the Wanderer
    [bridge.stl, centerback.stl, centerfront.stl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]
2025-03-14 Continuing work on the Wanderer
    [bridge.stl, left.stl, post.stl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]
2025-05-12 Added the Ikari
    [bottom.stl, ikari.blend, plate_left.stl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]
2025-08-16 Big changes
    [Body.stl, Bottom plate.stl, back.stl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]
2025-08-16 Remade the Ork
    [back.stl, bottom.stl, corner.stl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]
2025-08-16 Missing images
    [back panel.stl, bottom.stl, bridge.stl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]
2025-08-18 Goblin STL files
    [bottomleft.stl, bottomright.stl, left.stl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]
2025-08-24 New build: Raijin
    [bottom.stl, bracket.stl, corner.stl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]
2025-08-24 Added missing cut files
    [#back.dxf, HitBox.dxf, Sega 2P.dxf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]
2025-08-24 Forgot to update the corner post, whoops
    [corner.stl]
2025-12-16 Updated Wanderer with better tolerances (0.2mm -> 0.4mm)
    [bottom.stl, centerback.stl, centerfront.stl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]
2025-12-16 Oops wrong files
    [left.stl, right.stl]
2025-12-28 Added the Tteokbokki Top Grade
    [bottom_center.stl, bottom_leftright.stl, hb_left.stl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]
2025-12-30 Generally remade the case to be more extensible
    [bottom_center.stl, bottom_left.stl, bottom_leftright.stl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]
2026-04-07 Updated the Tteokbokki
    [left_full.stl, left_recessed.stl, plate_blank.stl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]
2026-04-07 Added a screw on option for the Tteokbokki
    [bottom_center.stl, bottom_left.stl, bottom_right.stl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]

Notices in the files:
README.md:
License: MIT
